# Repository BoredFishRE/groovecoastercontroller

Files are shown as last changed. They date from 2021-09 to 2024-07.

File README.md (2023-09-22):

# Groove Coaster Controller 2023 (Modified by Anthony Raudino)
This is a fork of the fork of the original project modified with some adjustments as well as acrylic cuts, custom prints as well as a custom PCB!

# This is a WIP as I refine things. Don't use the stick tubes from the CAD, they didn't convert well.

# WARNING!!! On the PCB, ground for the joysticks is pin 5, the pin on the connector all the way to the right. Your joystick may come with ground as pin 1, please make note of this.

* Original readme included in seperate file for anyone wanting to follow the original Teensy instructions, though I don't suggest it.

# Groove Coaster Controller
GrooveCoaster Controller replica with dimensions from real cabinet  
Box is 20 x 10 x 56.5 cm

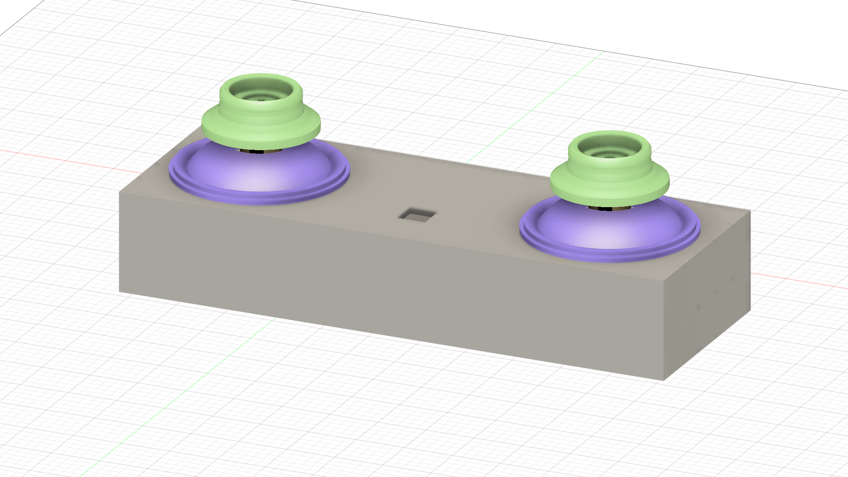
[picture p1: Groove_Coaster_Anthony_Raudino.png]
6mmcontroller

controller

# needed
- Microcontroller with an RP2040 (PCB is for sparkfun promicro 2040)
- a 3D printer
- a laser cutting machine
- 5mm plywood OR acrylic 
- 2 x seimitsu LS32-SE joysticks
- 2 x 60mm buttons
- A lot of screws, specific amount coming soon
- M3 heat set inserts, I suggest the CNC Kitchen since that's what I designed for.

# not needed, but suggested
 - 20g Sanwa springs (you need 2, but you can get a 10 pack easily)
 - 100g Omron V-10-1A4 x2 (for the 2 main buttons, you can get 3 if you want it on the start button, but you don't need it)

# things to 3d print
- 2 x joy_stick.stl
- 2 x joy_base.stl
- 2 x joy_tube.stl
- All the corner brackets. This will help in rigidity and assembly

# things to laser cut
- 2 x box_side.dxf
- 2 x box_insert.dxf (goes on box_middle, helps for rigidity)
- 1 x box_front.dxf
- 1 x box_back.dxf
- 1 x box_top.dxf
- 1 x box_middle.dxf
- 1 x box_bottom.dxf

# assembly
### COMING SOON

# soldering (If you're not using the PCB)
- Use schematic tbh.

# Firmware
- I will release soon, but I will be using GP2040-CE

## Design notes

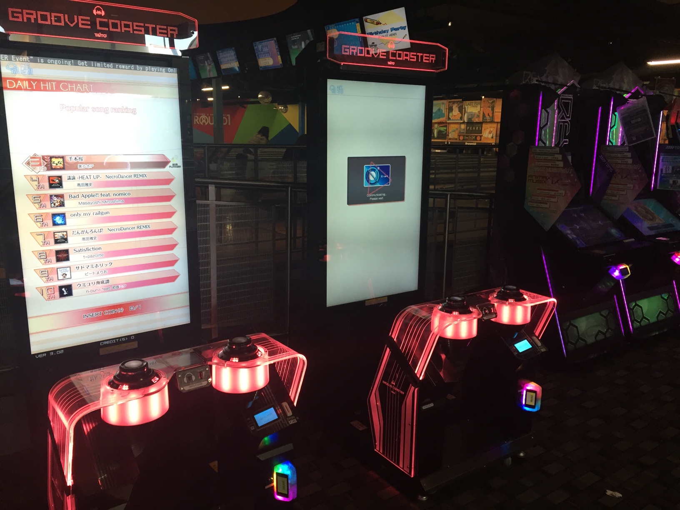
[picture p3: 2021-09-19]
Reference Pics/1461564461.7095.jpg

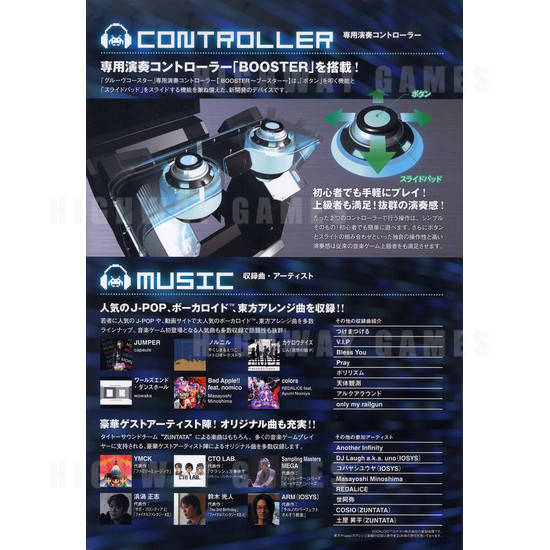
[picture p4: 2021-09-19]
Reference Pics/groove-coaster-arcade-machine-52028-16209.jpg

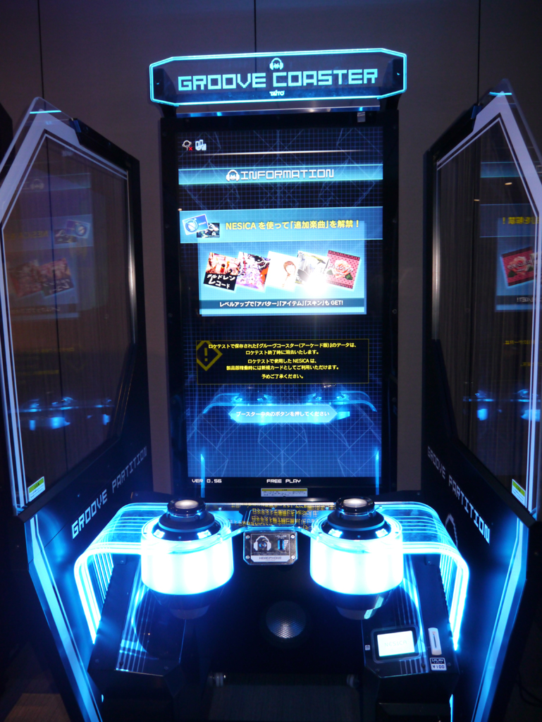
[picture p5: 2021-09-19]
Reference Pics/groovecoast1.jpg

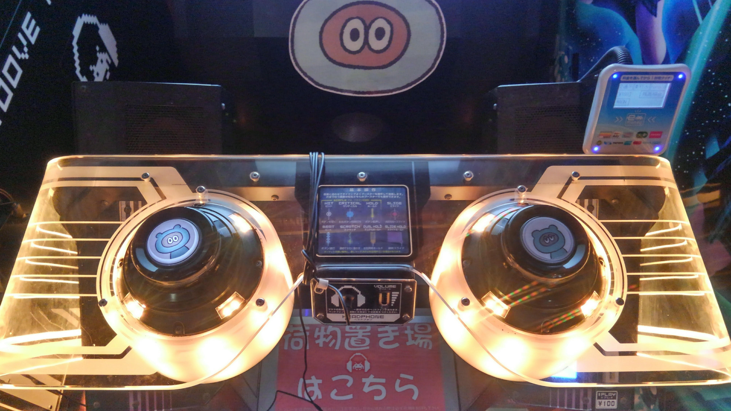
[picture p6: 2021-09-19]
Reference Pics/arcade controls overshot.jpg

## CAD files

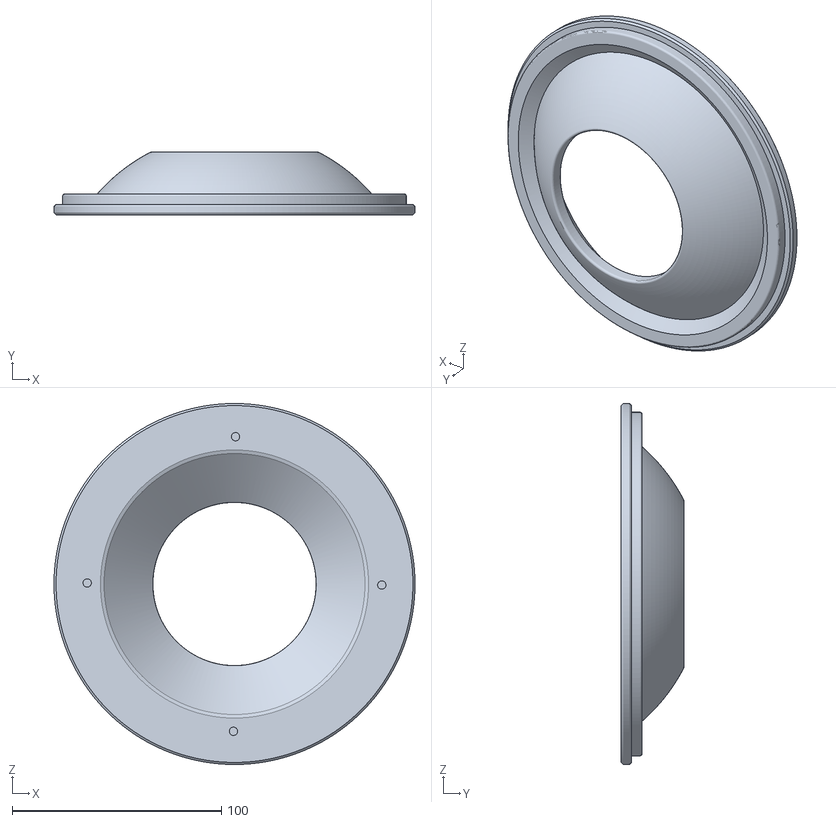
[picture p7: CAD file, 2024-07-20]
3DprintedParts/joy_base.STL
172.6 x 29.9 x 172.7

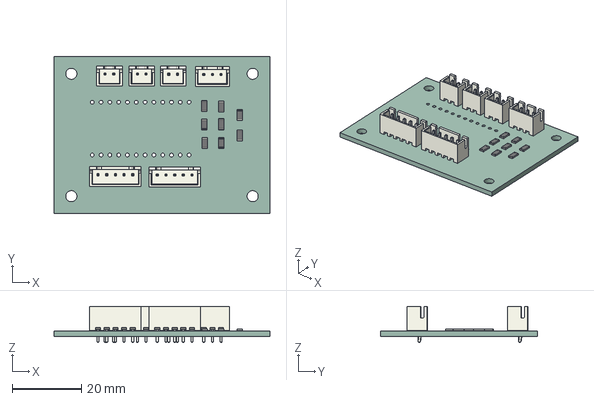
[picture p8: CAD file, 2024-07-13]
PCB/Groove Coaster.step
62.3 x 45.3 x 10.4 mm
PCB

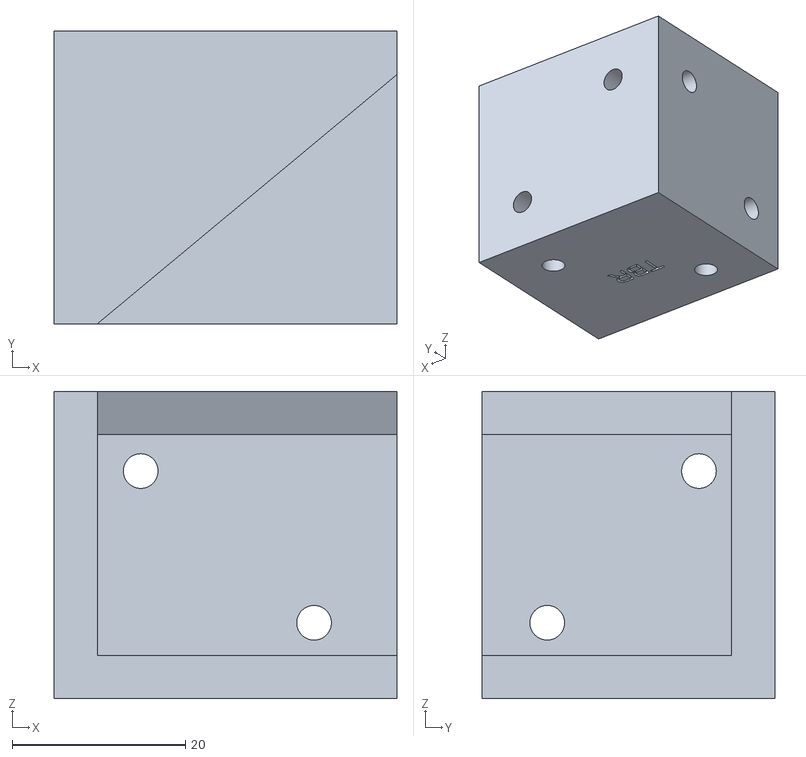
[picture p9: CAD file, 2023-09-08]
3DprintedParts/TBR.stl
39.6 x 33.8 x 35.4

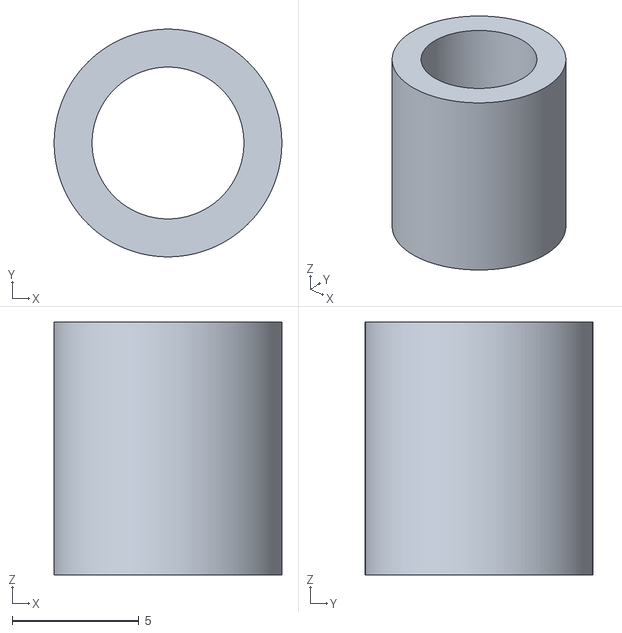
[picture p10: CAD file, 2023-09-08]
3DprintedParts/groovespacer.stl
9.00 x 9.00 x 10.0

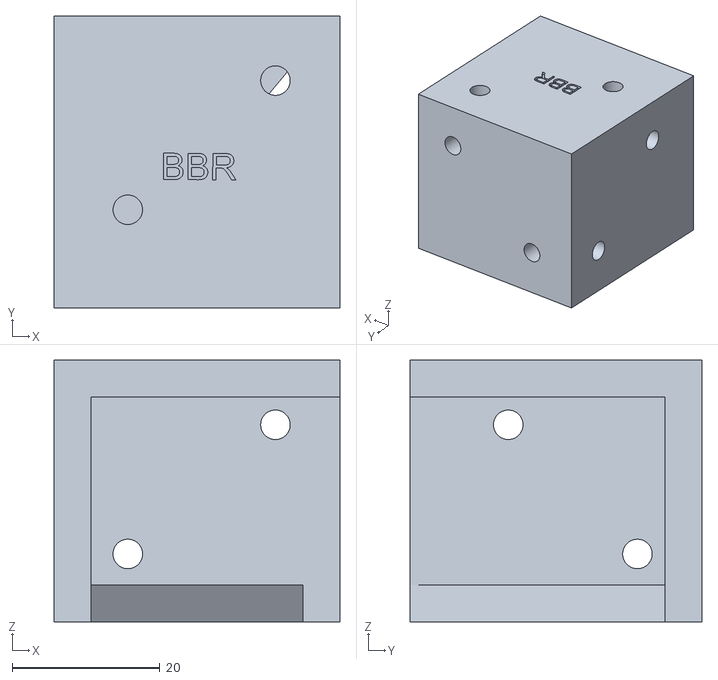
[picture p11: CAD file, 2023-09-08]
3DprintedParts/BBR.stl
38.8 x 39.6 x 35.4

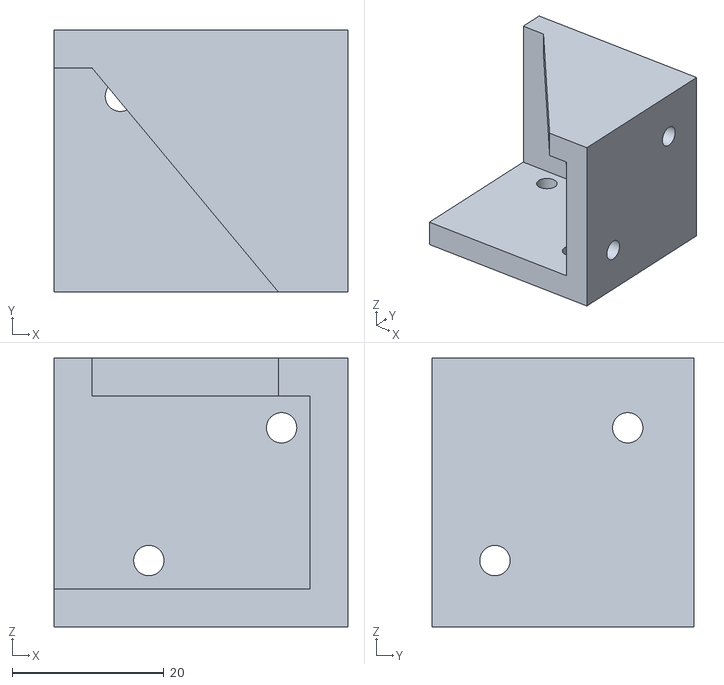
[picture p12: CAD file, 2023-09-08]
3DprintedParts/TBL.stl
38.8 x 34.6 x 35.4

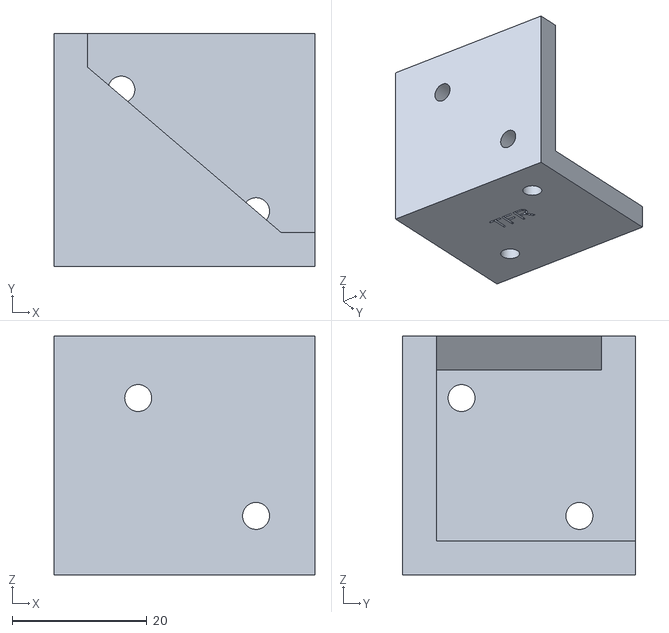
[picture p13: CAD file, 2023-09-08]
3DprintedParts/TFR.stl
38.8 x 34.6 x 35.4

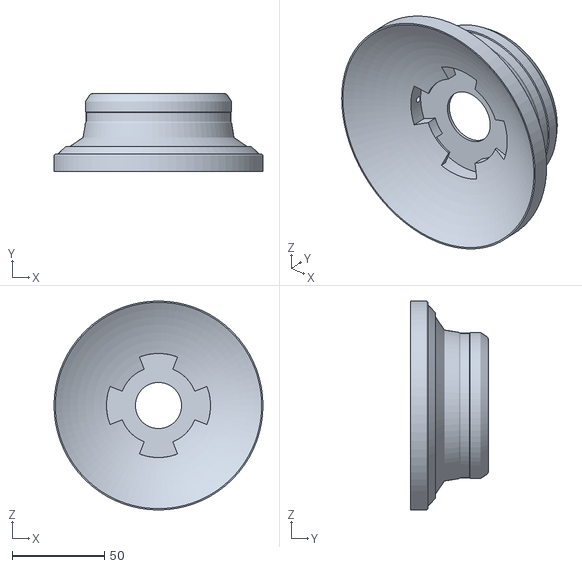
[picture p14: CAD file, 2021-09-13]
3DprintedParts/joy_stick.STL
113.3 x 42.0 x 113.3

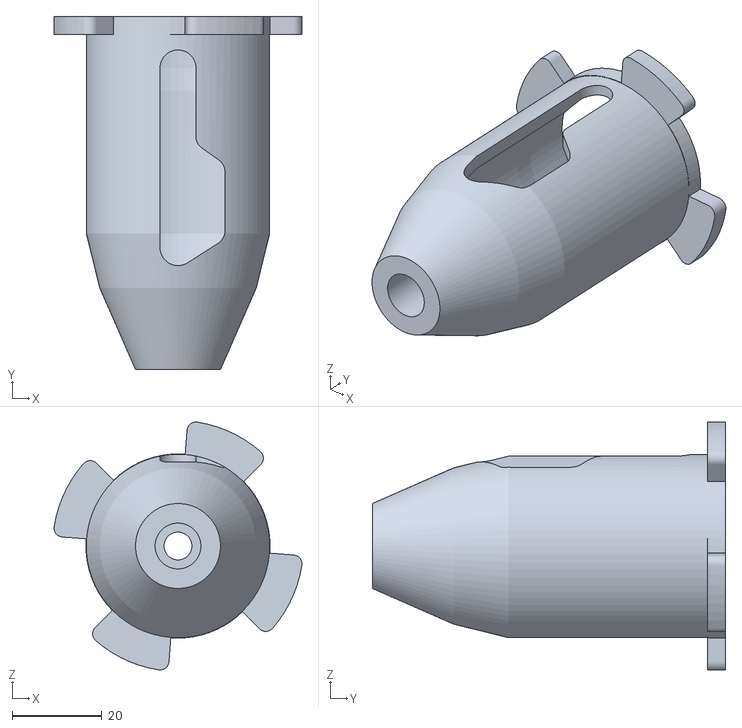
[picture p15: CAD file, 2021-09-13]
3DprintedParts/joy_tube.STL
55.2 x 78.7 x 55.2

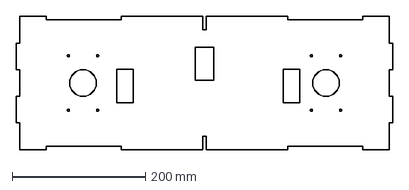
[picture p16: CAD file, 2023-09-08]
Box Laser Cut Files/box_middle_screws.DXF
565.0 x 200.0 mm

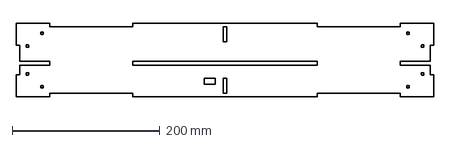
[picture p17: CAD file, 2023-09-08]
Box Laser Cut Files/box_back_screws.DXF
565.0 x 100.0 mm

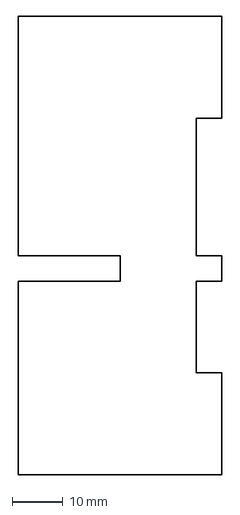
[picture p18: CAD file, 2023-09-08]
Box Laser Cut Files/box_insert_screws.DXF
40.0 x 90.0 mm

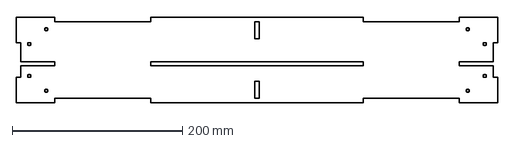
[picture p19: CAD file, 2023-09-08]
Box Laser Cut Files/box_front_screws.DXF
565.0 x 100.0 mm

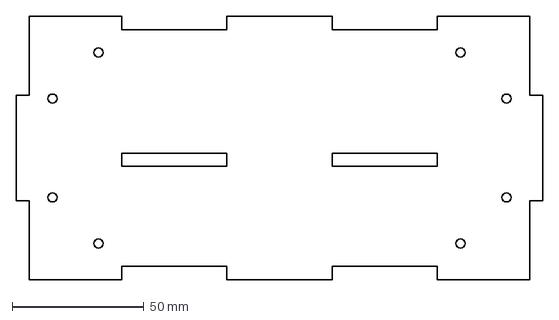
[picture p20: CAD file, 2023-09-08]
Box Laser Cut Files/box_side_screws.DXF
200.0 x 100.0 mm

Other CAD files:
3DprintedParts/TFL.stl
3DprintedParts/BFR.stl
3DprintedParts/BBL.stl
3DprintedParts/BFL.stl
Box Laser Cut Files/box_bottom_screws.DXF
Box Laser Cut Files/box_top_screws.DXF
Controller CAD/Groovetroller.f3z

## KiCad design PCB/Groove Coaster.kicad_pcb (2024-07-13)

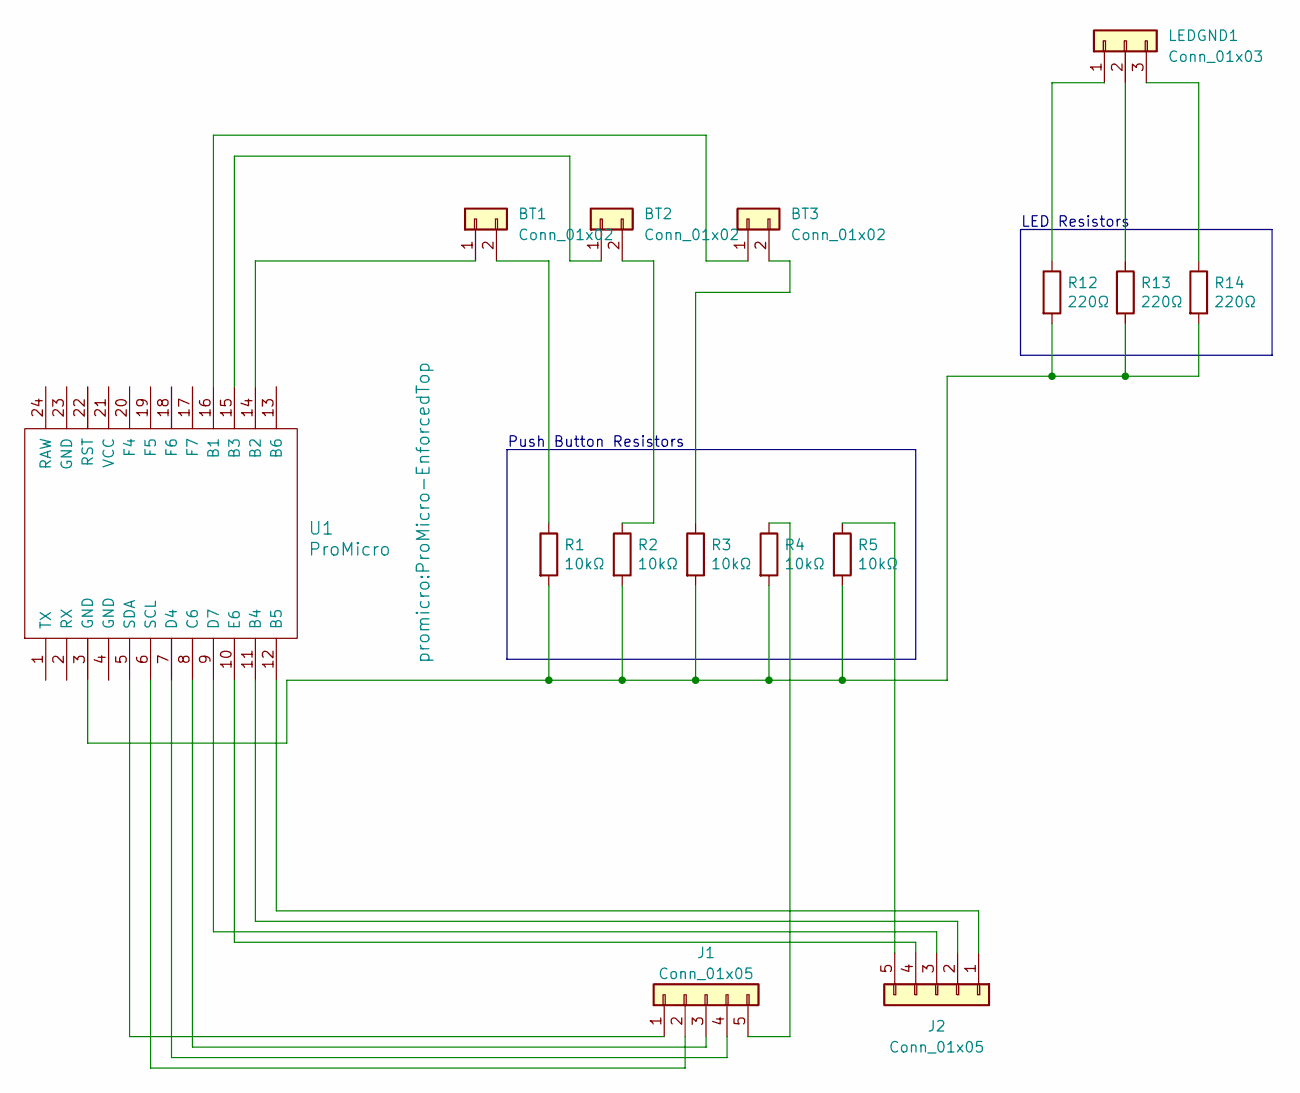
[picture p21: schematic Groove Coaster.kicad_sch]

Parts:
BT1, BT2, BT3: Conn_01x02; JST_XH_B2B-XH-A_1x02_P2.50mm_Vertical
J1, J2: Conn_01x05; JST_XH_B5B-XH-AM_1x05_P2.50mm_Vertical
LEDGND1: Conn_01x03; JST_XH_B3B-XH-A_1x03_P2.50mm_Vertical
R1, R2, R3, R4, R5: 10kΩ; R_1206_3216Metric
R12, R13, R14: 220Ω; R_1206_3216Metric
U1: ProMicro; ProMicro-EnforcedTop

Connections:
unnamed: BT1.1, U1.14 (B2)
unnamed: BT1.2, R1.1
unnamed: BT2.1, U1.15 (B3)
unnamed: BT2.2, R2.1
unnamed: BT3.1, U1.16 (B1)
unnamed: BT3.2, R3.1
unnamed: J1.1, U1.5 (SDA)
unnamed: J1.2, U1.6 (SCL)
unnamed: J1.3, U1.8 (C6)
unnamed: J1.4, U1.7 (D4)
unnamed: J1.5, R4.1
unnamed: J2.1, U1.12 (B5)
unnamed: J2.2, U1.11 (B4)
unnamed: J2.3, U1.9 (D7)
unnamed: J2.4, U1.10 (E6)
unnamed: J2.5, R5.1
unnamed: LEDGND1.1, R12.1
unnamed: LEDGND1.2, R13.1
unnamed: LEDGND1.3, R14.1
unnamed: R1.2, R2.2, R3.2, R4.2, R5.2, R12.2, R13.2, R14.2, U1.3 (GND)

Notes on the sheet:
LED Resistors
Push Button Resistors

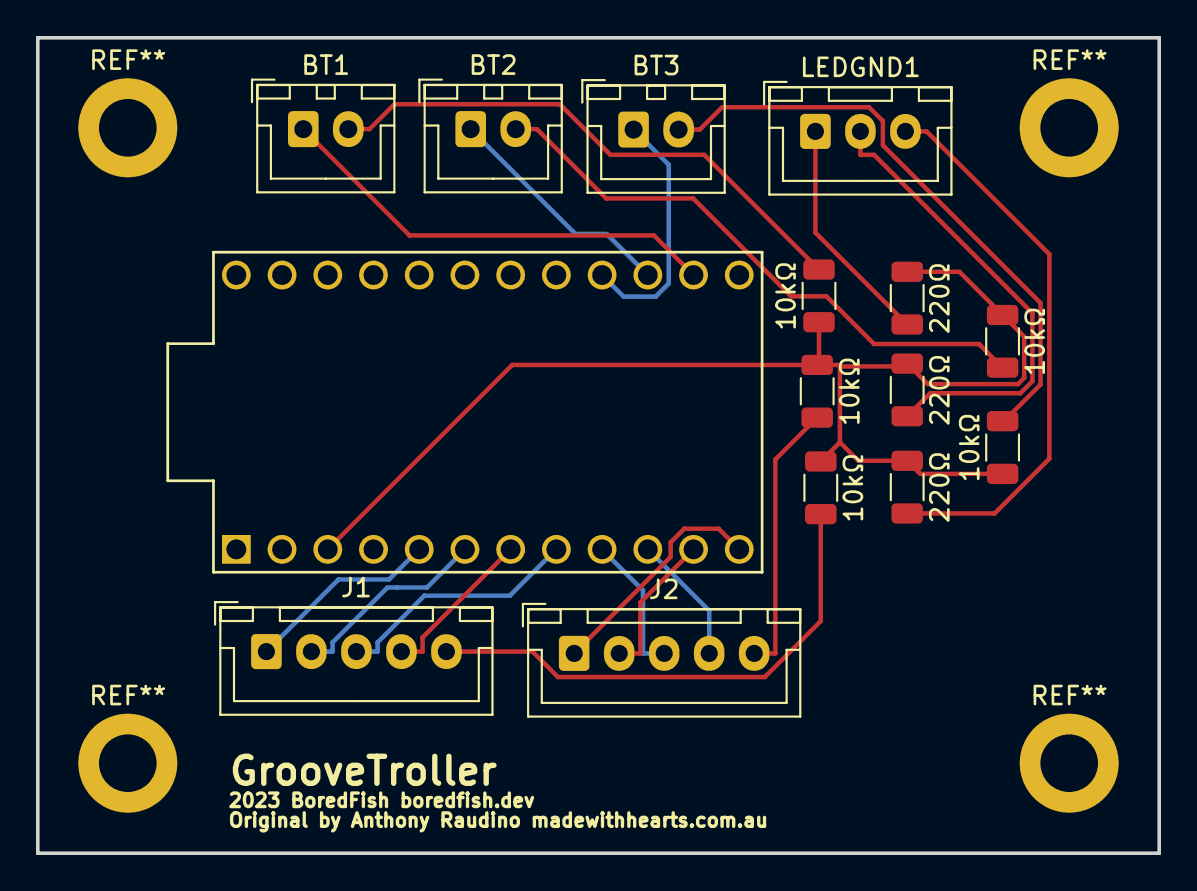
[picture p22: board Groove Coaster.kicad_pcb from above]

Board: 2 copper layers, 62.3 x 45.3 mm, 15 parts (0 on the bottom side), 20 nets.

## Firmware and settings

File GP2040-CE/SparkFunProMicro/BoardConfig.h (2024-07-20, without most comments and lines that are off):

#define PICO_BOARD_CONFIG_H_
#include "enums.pb.h"
#define BOARD_CONFIG_LABEL "SparkFun Pro Micro"
#define PIN_DPAD_UP 6    // UP
#define PIN_DPAD_DOWN 7  // DOWN
#define PIN_DPAD_LEFT 9  // LEFT
#define PIN_DPAD_RIGHT 8 // RIGHT
#define PIN_BUTTON_B3 5    // B3 / X     / Y       / Square   / 1  / P1
#define PIN_BUTTON_B1 3   // B1 / A     / B       / Cross    / 2  / K1
#define PIN_BUTTON_B2 4    // B2 / B     / A       / Circle   / 3  / K2
#define PIN_BUTTON_B4 2    // B4 / Y     / X       / Triangle / 4  / P2
#define PIN_BUTTON_L1 23    // L1 / LB    / L       / L1       / 5  / P4
#define PIN_BUTTON_R1 20   // R1 / RB    / R       / R1       / 6  / P3
#define PIN_BUTTON_L2 -1   // L2 / LT    / ZL      / L2       / 7  / K4
#define PIN_BUTTON_R2 -1   // R2 / RT    / ZR      / R2       / 8  / K3
#define PIN_BUTTON_S1 -1   // S1 / Back  / Minus   / Select   / 9  / Coin
#define PIN_BUTTON_S2 22   // S2 / Start / Plus    / Start    / 10 / Start
#define PIN_BUTTON_L3 -1   // L3 / LS    / LS      / L3       / 11 / LS
#define PIN_BUTTON_R3 -1   // R3 / RS    / RS      / R3       / 12 / RS
#define PIN_BUTTON_A1 -1    // A1 / Guide / Home    / PS       / 13 / ~
#define PIN_BUTTON_A2 -1   // A2 / ~     / Capture / ~        / 14 / ~
#define PIN_BUTTON_FN -1   // Hotkey Function
#define PIN_BUTTON_REVERSE -1 // UDLR Reverse
#define PIN_BUTTON_TURBO -1 // Turbo
#define PIN_SLIDER_ONE -1   // Left Stick Slider
#define PIN_SLIDER_TWO -1   // Right Stick Slider
#define DEFAULT_SOCD_MODE SOCD_MODE_NEUTRAL
#define SLIDER_SOCD_SLOT_ONE SOCD_MODE_UP_PRIORITY
#define SLIDER_SOCD_SLOT_TWO  SOCD_MODE_SECOND_INPUT_PRIORITY
#define SLIDER_SOCD_SLOT_DEFAULT SOCD_MODE_NEUTRAL
#define DEFAULT_FORCED_SETUP_MODE FORCED_SETUP_MODE_OFF // 	FORCED_SETUP_MODE_OFF, FORCED_SETUP_MODE_LOCK_MODE_SWITCH, FORCED_SETUP_MODE_LOCK_WEB_CONFIG, FORCED_SETUP_MODE_LOCK_BOTH
#define DEFAULT_LOCK_HOTKEYS false // or true
#define DEFAULT_PS4CONTROLLER_TYPE PS4_CONTROLLER
#define TURBO_LED_PIN -1
#define BOARD_LEDS_PIN -1
#define LED_BRIGHTNESS_MAXIMUM 50
#define LED_BRIGHTNESS_STEPS 5
#define LED_FORMAT LED_FORMAT_GRB
#define LEDS_PER_PIXEL 1
#define LEDS_DPAD_LEFT -1
#define LEDS_DPAD_DOWN -1
#define LEDS_DPAD_RIGHT -1
#define LEDS_DPAD_UP -1
#define LEDS_BUTTON_B3 -1
#define LEDS_BUTTON_B4 -1
#define LEDS_BUTTON_R1 -1
#define LEDS_BUTTON_L1 -1
#define LEDS_BUTTON_B1 -1
#define LEDS_BUTTON_B2 -1
#define LEDS_BUTTON_R2 -1
#define LEDS_BUTTON_L2 -1
#define PLED_TYPE PLED_TYPE_NONE
#define PLED1_PIN -1
#define PLED2_PIN -1
#define PLED3_PIN -1
#define PLED4_PIN -1
#define ANALOG_ADC_1_VRX -1
#define ANALOG_ADC_1_VRY -1
#define ANALOG_ADC_1_MODE DPAD_MODE_LEFT_ANALOG
#define ANALOG_ADC_1_INVERT INVERT_NONE
#define ANALOG_ADC_2_VRX -1
#define ANALOG_ADC_2_VRY -1
#define ANALOG_ADC_2_MODE DPAD_MODE_RIGHT_ANALOG
#define ANALOG_ADC_2_INVERT INVERT_NONE
#define REVERSE_LED_PIN -1
#define HAS_I2C_DISPLAY 0
#define I2C_SDA_PIN 0
#define I2C_SCL_PIN 1
#define I2C_BLOCK i2c0
#define I2C_SPEED 400000
#define DISPLAY_FLIP 0
#define DISPLAY_INVERT 0
#define REVERSE_UP_DEFAULT 1
#define REVERSE_DOWN_DEFAULT 1
#define REVERSE_LEFT_DEFAULT 1
#define REVERSE_RIGHT_DEFAULT 1
#define BUTTON_LAYOUT BUTTON_LAYOUT_STICK
#define BUTTON_LAYOUT_RIGHT BUTTON_LAYOUT_VEWLIX
#define SPLASH_MODE SPLASH_MODE_NONE
#define SPLASH_CHOICE SPLASH_CHOICE_MAIN
#define SPLASH_DURATION 7500 // Duration in milliseconds
#define BOARD_LED_TYPE ON_BOARD_LED_MODE_OFF
#define PIN_DUAL_DIRECTIONAL_UP -1
#define PIN_DUAL_DIRECTIONAL_DOWN -1
#define PIN_DUAL_DIRECTIONAL_LEFT -1
#define PIN_DUAL_DIRECTIONAL_RIGHT -1
#define DUAL_DIRECTIONAL_STICK_MODE DPAD_MODE_DIGITAL
#define DUAL_DIRECTIONAL_COMBINE_MODE DUAL_COMBINE_MODE_MIXED
#define BOOTSEL_BUTTON_MASK 0 // 0 means none, get other mask from GamepadState.h
#define EXTRA_BUTTON_MASK 0 // 0 means none, get other mask from GamepadState.h
#define EXTRA_BUTTON_PIN -1
#define KEY_DPAD_UP     HID_KEY_ARROW_UP      // UP
#define KEY_DPAD_DOWN   HID_KEY_ARROW_DOWN    // DOWN
#define KEY_DPAD_RIGHT  HID_KEY_ARROW_RIGHT   // RIGHT
#define KEY_DPAD_LEFT   HID_KEY_ARROW_LEFT    // LEFT
#define KEY_BUTTON_B1   HID_KEY_SHIFT_LEFT    // B1 / A / B / Cross / 2 / K1
#define KEY_BUTTON_B2   HID_KEY_Z             // B2 / B / A / Circle / 3 / K2
#define KEY_BUTTON_R2   HID_KEY_X             // R2 / RT / ZR / R2 / 8 / K3
#define KEY_BUTTON_L2   HID_KEY_V             // L2 / LT / ZL / L2 / 7 / K4
#define KEY_BUTTON_B3   HID_KEY_CONTROL_LEFT  // B3 / X / Y / Square / 1 / P1
#define KEY_BUTTON_B4   HID_KEY_ALT_LEFT      // B4 / Y / X / Triangle / 4 / P2
#define KEY_BUTTON_R1   HID_KEY_SPACE         // R1 / RB / R / R1 / 6 / P3
#define KEY_BUTTON_L1   HID_KEY_C             // L1 / LB / L / L1 / 5 / P4
#define KEY_BUTTON_S1   HID_KEY_5             // S1 / Back / Minus / Select / 9 / Coin
#define KEY_BUTTON_S2   HID_KEY_1             // S2 / Start / Plus / Start / 10 / Start
#define KEY_BUTTON_L3   HID_KEY_EQUAL         // L3 / LS / LS / L3 / 11 / LS
#define KEY_BUTTON_R3   HID_KEY_MINUS         // R3 / RS / RS / R3 / 12 / RS
#define KEY_BUTTON_A1   HID_KEY_9             // A1 / Guide / Home / PS / 13 / ~
#define KEY_BUTTON_A2   HID_KEY_F2            // A2 / ~ / Capture / ~ / 14 / ~

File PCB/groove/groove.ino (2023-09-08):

#include <Gamepad.h>
Gamepad gp;
void setup() {
  // put your setup code here, to run once:
  pinMode(16, INPUT_PULLUP);
  pinMode(15, INPUT_PULLUP);
  pinMode(14, INPUT_PULLUP);
  pinMode(2, INPUT_PULLUP);
  pinMode(3, INPUT_PULLUP);
  pinMode(4, INPUT_PULLUP);
  pinMode(5, INPUT_PULLUP);
  pinMode(6, INPUT_PULLUP);
  pinMode(7, INPUT_PULLUP);
  pinMode(8, INPUT_PULLUP);
  pinMode(9, INPUT_PULLUP);
}
void loop() {
  int UP, DOWN, LEFT, RIGHT, X, Y, A, B;
  UP = digitalRead(2);
  DOWN = digitalRead(3);
  LEFT = digitalRead(4);
  RIGHT = digitalRead(5);
  X = digitalRead(7);
  Y = digitalRead(9);
  A = digitalRead(8);
  B = digitalRead(6);
  if (UP == LOW)
    gp.setButtonState(2, true);
  else
    gp.setButtonState(2, false);

  if (DOWN == LOW)
    gp.setButtonState(3, true);
  else
    gp.setButtonState(3, false);

  if (LEFT == LOW)
    gp.setButtonState(4, true);
  else
    gp.setButtonState(4, false);

  if (RIGHT == LOW)
    gp.setButtonState(5, true);
  else
    gp.setButtonState(5, false);

  if (X == LOW)
    gp.setButtonState(8, true);
  else
    gp.setButtonState(8, false);

  if (Y == LOW)
    gp.setButtonState(9, true);
  else
    gp.setButtonState(9, false);

  if (A == LOW)
    gp.setButtonState(10, true);
  else
    gp.setButtonState(10, false);

  if (B == LOW)
    gp.setButtonState(11, true);
  else
    gp.setButtonState(11, false);

  delay(20);
}

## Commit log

2021-09-13 cleaned up project
    [box_bottom.DXF, box_front.DXF, box_insert.DXF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]
2021-09-20 created single file cut layout and panel with USB C port hole
2021-09-20 Create box_middle WITH CABLE RUN HOLES.ai
2021-09-22 pcb things
    [Groove Coaster.kicad_pcb, Groove Coaster.sch]
2021-09-29 rebuilt box in 6mm in fusion 360 and created 6mm compatible laser cut files
    [Groove Coaster Laser Cuts 6mm FINAL.dxf, Groove Coaster Laser Cuts 6mm.dxf, Groove Coaster v14.f3d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]
2021-09-29 renamed cad image
2021-10-03 added square button hole
    [Groove Coaster Laser Cuts 6mm FINAL.dxf, box_top-6mm.dxf]
2023-09-08 All da changes
    [BBL.stl, BBR.stl, BFL.stl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]
2024-07-20 Fix Base Ring
    old prevented diagonal movements from working so this one fixes that issue.
    [joy_base.STL]
